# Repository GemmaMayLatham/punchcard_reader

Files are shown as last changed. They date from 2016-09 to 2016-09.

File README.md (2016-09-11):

Arduino/Raspberry Pi Punchcard reader
====

Here are the code files for the Minecraft Punchcard Reader.

This is a small box that you feed hand-punched pieces of card into
with patterns punched on them, and the program will build those patterns
inside Minecraft for you!

The Python code runs on Raspberry Pi, PC or Mac.

For a good write-up of what this project does and some really nice
photos of it in use, please see Gemma Latham's blog post here:

[Gemma's blog] (http://www.gemmamaylatham.co.uk/portfolio-item/patterncraft/)

For those of you following along with this project live, you can build
your own PunchCard reader from the materials on this website and by
looking at the photos that Gemma has posted on her blog. We hope to write
the build instructions up in detail over summer.

Inside this github repo, you will find the arduino source code for an
Arduino Pro Micro. I buy these from here:

[Sparkfun ProMicro] (http://skpang.co.uk/catalog/pro-micro-33v8mhz-with-headers-and-anyio-firmware-p-1327.html)

Inside the box I used two pieces of veroboard cut and bolted back to back
with the copper facing outwards, drilled 9 holes to line up with the
holes in the punchcard, and soldered IR transmitter LEDs on one side of
the board, and IR filtered photo transistors on the other. The LED's
and photo transistors point through the holes in the board. The Arduino
Pro-Micro then uses it's 9 analog inputs to read the voltage from each
of the Photo Transistors, and work out where the holes are in the card.

I bought these parts, 9 of each, and used 1K resistors in line with
each of them to limit the current that flows through them to an acceptable
value.

IR Transmitter LED:

[OSRAM SFH484-2] (http://uk.farnell.com/webapp/wcs/stores/servlet/ProductDisplay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)

(Note, this is now being obsoleted, use this replacement part)

[OSRAM-SFG4550] (http://uk.farnell.com/osram/sfh4550/led-ir-5mm-850nm/dp/1573495)

This replacement part is 850nm compared to the phototransistor which is 880nm,
but the spectrum overlaps enough and the two devices are only a couple of
milimeters apart, so it still works fine.

IR receiver Phototransistor:

[Fairchild QSD123] (http://uk.farnell.com/webapp/wcs/stores/servlet/ProductDisplay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)

When the card is fed in and removed, a small string of hex numbers
is sent via a serial port using PySerial at the Python end to read
these numbers. They are then decoded into CSV data and written to a text
file.

Gemma then modified Adventure 6 from the book Adventures in Minecraft
to read that file and build shapes facing upwards inside Minecraft.

I based most of the python code on the anyio library that I wrote for
the electronics chapter in the book: Adventures in Minecraft. The firmware
in the ProMicro is loaded with the firmware of this project, but it
basically works using the same techniques.

Flashing the code
====

Note that this code is only tested using Arduino IDE 1.0.5 with the 
SparkFun ProMicro from here:

https://www.sparkfun.com/products/12587

***since running ok using Arduino IDE 1.6.10

Work In Progress
====

The new all-digital code is now finished and working on the ProMicro,
and this gives us a path forward to any arduino, regardless of whether
it has any analog ports or not (we don't use them any more),
and any bit width from 1 to 8 bits (plus the necessary registration
channel that is used to sense card insertion and removal, and
blank lines with no holes punched).

The TODO list consists of:

1. Getting code running on an ATTiny85 for the one bit reader

2. Getting code running on an ATMega328P (the DIL chip as taken off
of an Arduino Uno or a Gertboard)

3. Getting the serial interface on both of the above wired up to the 
3.3V UART on the Raspberry Pi. (It should then just work out of the
box with the existing code, providing portscan.cache has the value
/dev/ttyAMA0, the config.txt has the console disabled on this port,
and the initab has the getty disabled on that port.

Note that for correctly configuring the GPIO serial port on the
Raspberry Pi, I have a ttyedit.pyc file inside this other project
that I plan to import here in source format when I have tested
everything. The script automatically checks and removes the 
console from config.txt and checks and removes the getty on the
console from initab then reboots for you:

http://blog.whaleygeek.co.uk/raspberry-pi-neopixels-colour-mixer/

The compatibility with Raspberry Pi 3 GPIO serial is yet to be
characterised, I know that they moved the uart for addition of
bluetooth, and the uart mapped to the GPIO pins used to suffer
from unexplained speed changes. This *might* have been fixed
in newer kernel releases, but I haven't tried it yet.

David Whale
@whaleygeek
June 2015

Updated May 2016

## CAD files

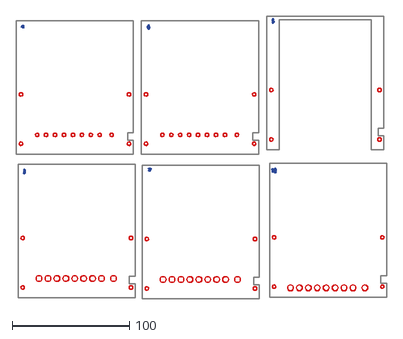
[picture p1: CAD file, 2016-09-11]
Laser files/Reader Layers 1.5mm sept.dxf
316.0 x 241.1

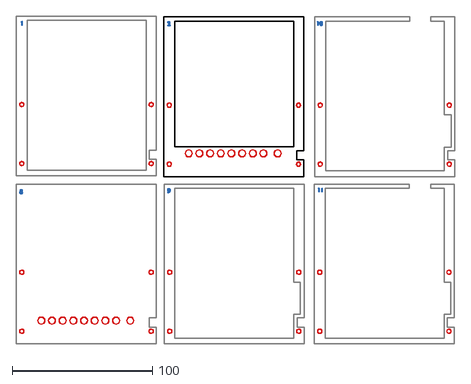
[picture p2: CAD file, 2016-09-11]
Laser files/Reader Layers 3mm sept.dxf
313.0 x 233.8

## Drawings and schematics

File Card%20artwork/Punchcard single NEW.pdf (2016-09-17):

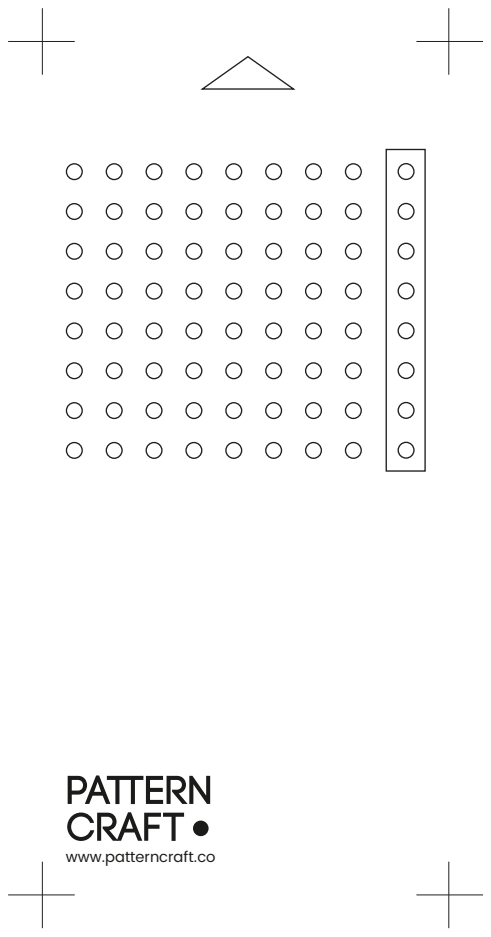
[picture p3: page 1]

www.patterncraft.co

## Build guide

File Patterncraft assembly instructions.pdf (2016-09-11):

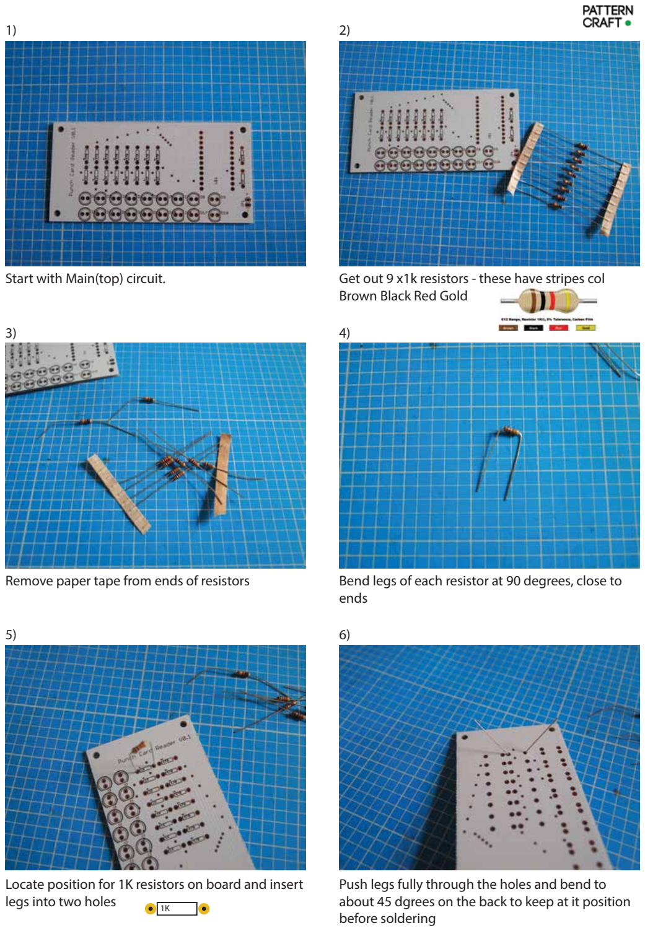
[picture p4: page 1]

Start with Main(top) circuit. | Get out 9 x1k resistors - these have stripes col Brown Black Red Gold
Remove paper tape from ends of resistors | Bend legs of each resistor at 90 degrees, close to ends

Locate position for 1K resistors on board and insert legs into two holes

Push legs fully through the holes and bend to about 45 dgrees on the back to keep at it position before soldering

1K

1) 2)
3) 4)
5) 6)

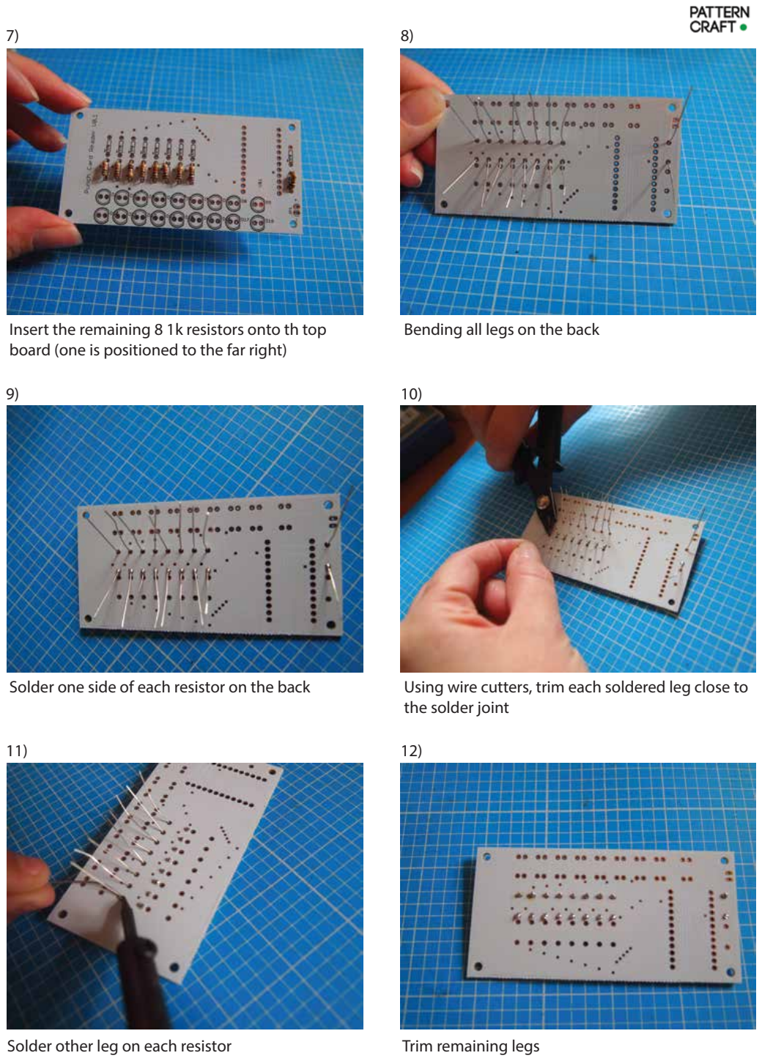
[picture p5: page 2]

Insert the remaining 8 1k resistors onto th top board (one is positioned to the far right)

Bending all legs on the back

Solder one side of each resistor on the back | Using wire cutters, trim each soldered leg close to the solder joint
Solder other leg on each resistor | Trim remaining legs
7) 8)
9) 10)
11) 12)

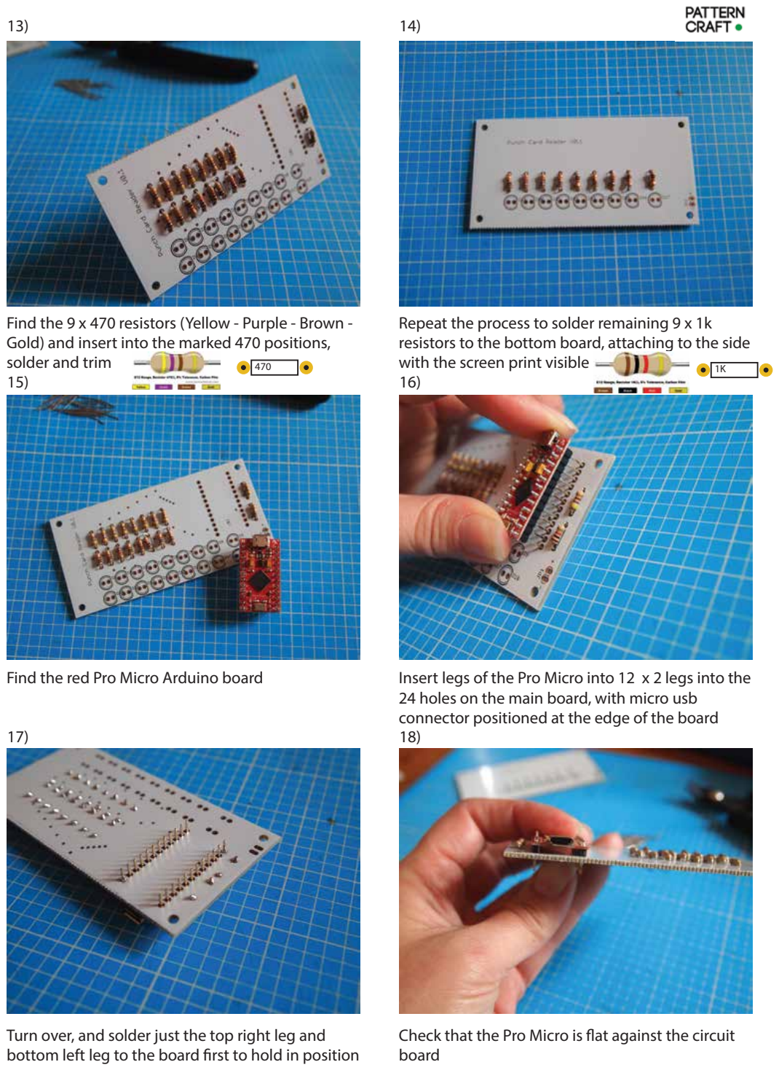
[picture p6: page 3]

Find the 9 x 470 resistors (Yellow - Purple - Brown -Gold) and insert into the marked 470 positions, solder and trim

Repeat the process to solder remaining 9 x 1k resistors to the bottom board, attaching to the side with the screen print visible

Find the red Pro Micro Arduino board | Insert legs of the Pro Micro into 12 x 2 legs into the 24 holes on the main board, with micro usb connector positioned at the edge of the board

Turn over, and solder just the top right leg and bottom left leg to the board rst to hold in position

Check that the Pro Micro is at against the circuit board

470 | 1K
13) 14)
15) 16)
17) 18)

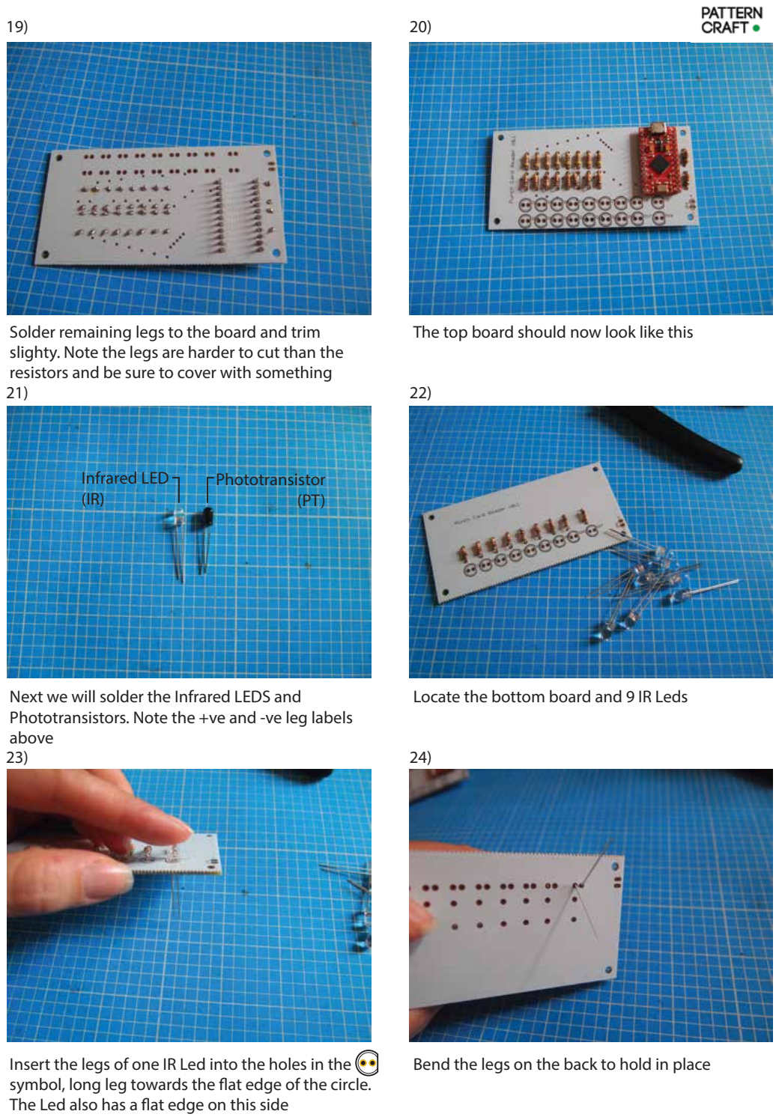
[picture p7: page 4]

Solder remaining legs to the board and trim slighty. Note the legs are harder to cut than the resistors and be sure to cover with something

The top board should now look like this

Next we will solder the Infrared LEDS and Phototransistors. Note the +ve and -ve leg labels above

Locate the bottom board and 9 IR Leds

Insert the legs of one IR Led into the holes in the symbol, long leg towards the at edge of the circle. The Led also has a at edge on this side

Bend the legs on the back to hold in place

Infrared LED
(IR)

Phototransistor
(PT)
19) 20)
21) 22)
23) 24)

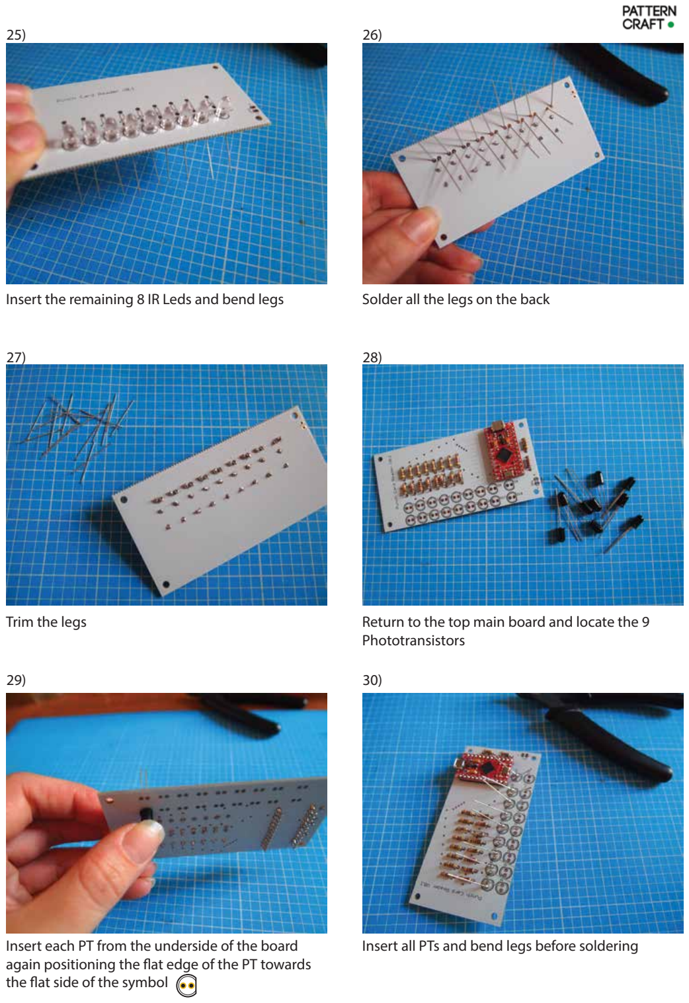
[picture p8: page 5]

Insert the remaining 8 IR Leds and bend legs | Solder all the legs on the back
Trim the legs | Return to the top main board and locate the 9 Phototransistors

Insert each PT from the underside of the board again positioning the at edge of the PT towards the at side of the symbol

Insert all PTs and bend legs before soldering

25) 26)
27) 28)
29) 30)

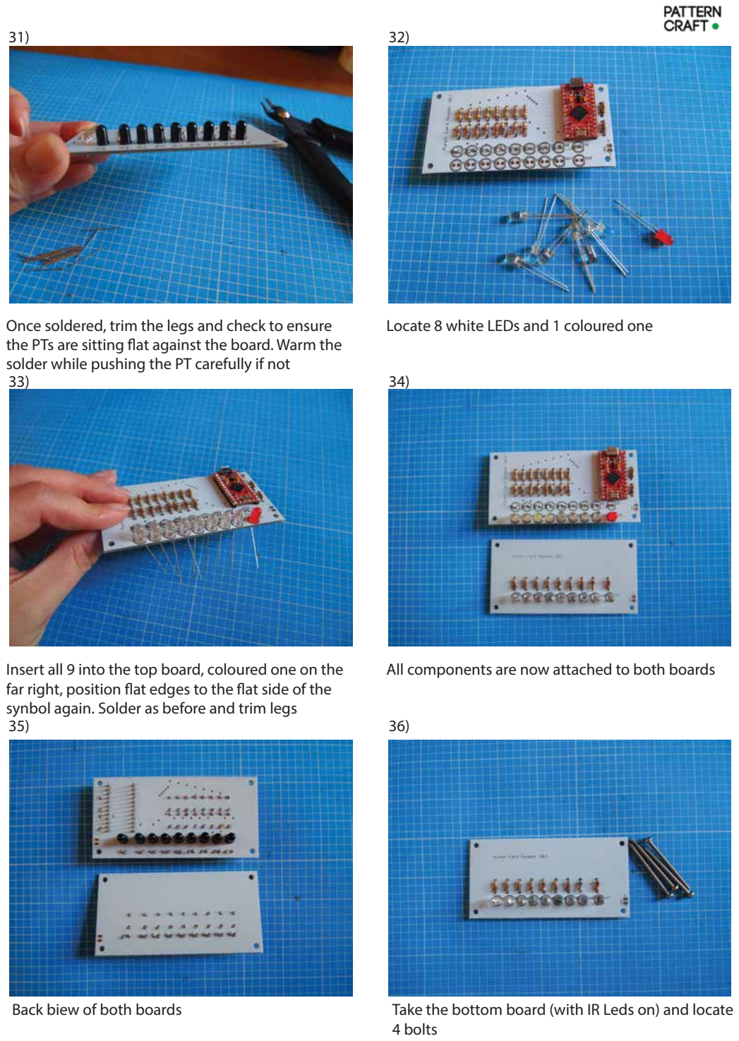
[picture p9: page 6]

Once soldered, trim the legs and check to ensure the PTs are sitting at against the board. Warm the solder while pushing the PT carefully if not

Locate 8 white LEDs and 1 coloured one

Insert all 9 into the top board, coloured one on the far right, position at edges to the at side of the synbol again. Solder as before and trim legs

All components are now attached to both boards

Back biew of both boards | Take the bottom board (with IR Leds on) and locate 4 bolts
31) 32)
33) 34)
35) 36)

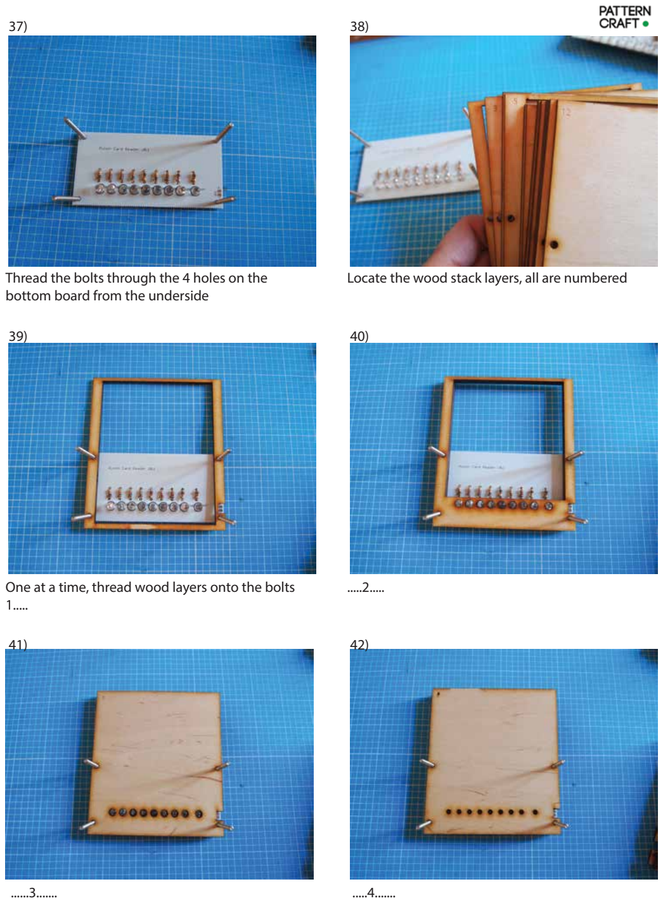
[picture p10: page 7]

Thread the bolts through the 4 holes on the bottom board from the underside

Locate the wood stack layers, all are numbered

One at a time, thread wood layers onto the bolts 1.....

.....2.....

......3....... | .....4.......
37) 38)
39) 40)
41) 42)

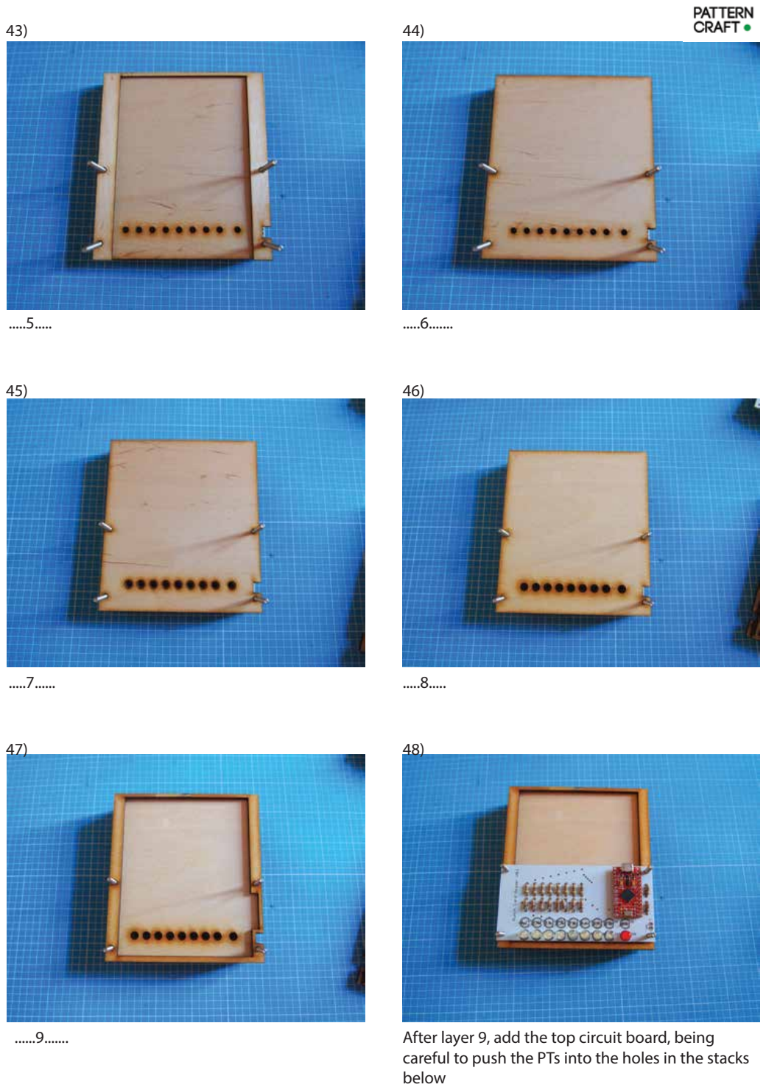
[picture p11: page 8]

.....5..... | .....6.......
.....7...... | .....8.....
......9....... | After layer 9, add the top circuit board, being careful to push the PTs into the holes in the stacks below
43) 44)
45) 46)
47) 48)

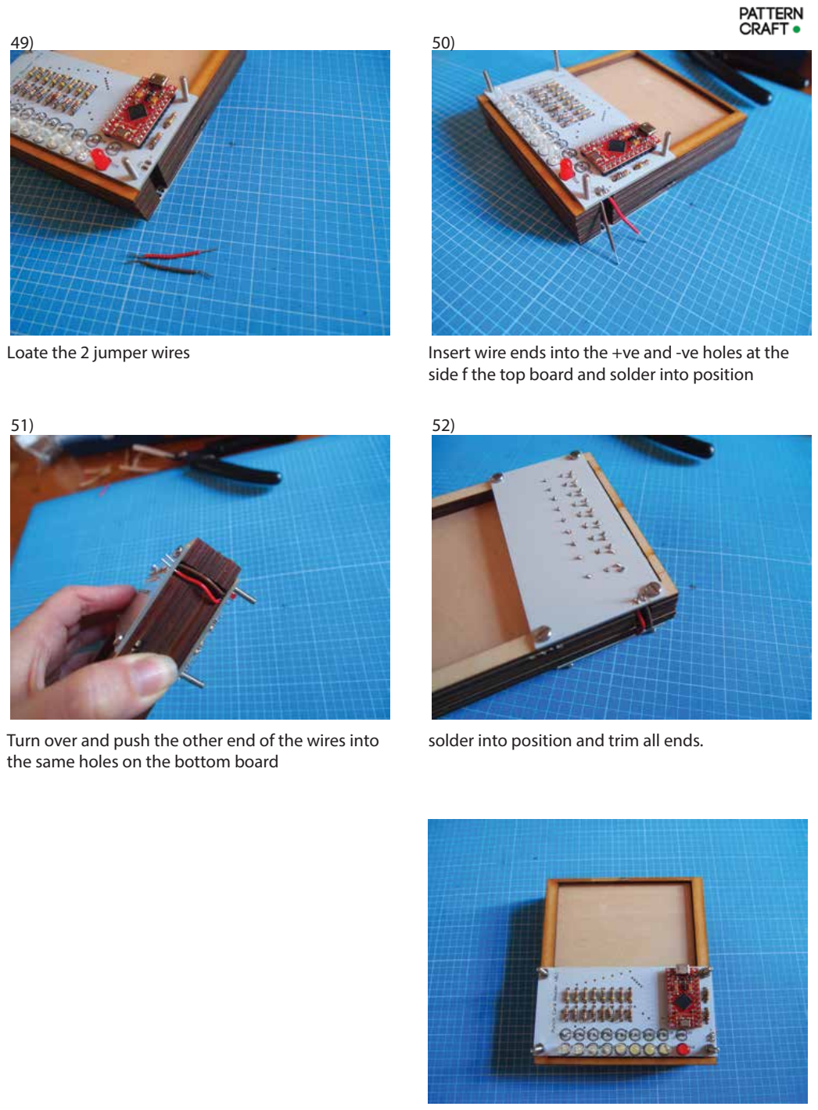
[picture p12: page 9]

Loate the 2 jumper wires | Insert wire ends into the +ve and -ve holes at the side f the top board and solder into position

Turn over and push the other end of the wires into the same holes on the bottom board

solder into position and trim all ends.

49) 50)
51) 52)

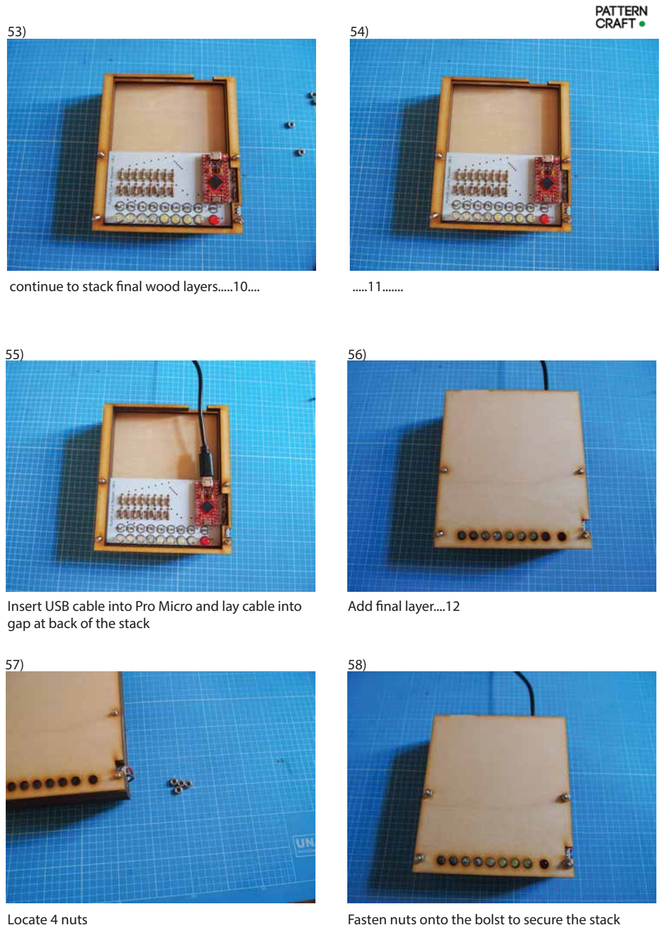
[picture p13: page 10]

Insert USB cable into Pro Micro and lay cable into gap at back of the stack

Add nal layer....12

Locate 4 nuts | Fasten nuts onto the bolst to secure the stack
continue to stack nal wood layers.....10.... | .....11.......
53) 54)
55) 56)
57) 58)

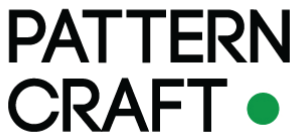
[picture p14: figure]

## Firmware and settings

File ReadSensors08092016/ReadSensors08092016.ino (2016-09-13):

// ReadSensors.ino  20/06/2015  D.J.Whale
//
// (c) 2015 D.J.Whale

// punching
// punch data in the 8 columns
// if you want an empty row, punch the REG hole
// don't punch all 8+REG else it will see a card removal


//TODO: add a record type that shows min/max values for zero's and ones on the last read
//this will be helpful to be able to diagnose problems in the field.
//min/max 1/0 for all 9 channels, in case of sensor misallignment.

// The ADC is 10 bit (0..1023)
// The photo transistors conduct when they detect IR
// So a HOLE will make the transistor conduct, current will flow, and
// the voltage at the ADC will drop, giving a value lower than this reading.
// When no card is present, all photo transistors will conduct and draw current.
// <  200 = HOLE  = 1
// >= 200 = PAPER = 0

#define CFG_SENSOR_THRESHOLD 512

//Turn on to send a raw ADC value report every time it changes
//#define CFGEN_SEND_ADC_REPORTS

//Turn this on to turn a state change report every state change
//#define CFGEN_SEND_STATE_REPORTS

//Turn this on to send row data reports every detected row
//#define CFGEN_SEND_ROW_REPORTS

// Pinouts for Sparkfun ProMicro:
// https://learn.sparkfun.com/tutorials/pro-micro--fio-v3-hookup-guide/hardware-overview-pro-micro

#define NUM_CHANNELS 9
#define REG          8  // A8
#define D7           7  // 7
#define D6           6  // A7
#define D5           5  // 5
#define D4           4  // A6
#define D3           3  // 3
#define D2           2  // 2
#define D1           0  // RX
#define D0           1  // TX

#define LED_REG      A3 // 21
#define LED_D7       A2 // 20
#define LED_D6       A1 // 19
#define LED_D5       A0 // 18
#define LED_D4       15 // SCLK
#define LED_D3       14 // MISO
#define LED_D2       16 // MOSI
#define LED_D1       10 // A10
#define LED_D0       9  // A9

// Set to 8, will only read IN phase
// Set to 16, will read and collect OUT phase also
// Must see all CARD_ROWS rows to get a OK report
// if less rows read, will get an error, but data still included
// This allows host to compare IN and OUT phases and error correct
#define CARD_ROWS    16

#define REPORT_OK_BOOT       0x00
#define REPORT_OK_CARD       0x01
#define REPORT_OK_STATE      0x02
#define REPORT_OK_ROW        0x03
#define REPORT_OK_ADC        0x04
#define REPORT_ERR_LENGTH    0x81

typedef enum 
{
  STATE_NOCARD = 0,
  STATE_INSERTING,
  STATE_WAITING_ROW,
  STATE_IN_ROW,
  STATE_GAP,
  STATE_REMOVING,
  STATE_END
} STATE;

byte sticky = 0;
boolean seenReg = false;
byte row = 0;
byte card[CARD_ROWS];
unsigned int adc[NUM_CHANNELS];
STATE state = STATE_NOCARD;
STATE prev = STATE_NOCARD;


void setup()
{
  Serial.begin(115200);  
  
  pinMode(LED_REG, OUTPUT);
  pinMode(LED_D7,  OUTPUT);
  pinMode(LED_D6,  OUTPUT);
  pinMode(LED_D5,  OUTPUT);
  pinMode(LED_D4,  OUTPUT);
  pinMode(LED_D3,  OUTPUT);
  pinMode(LED_D2,  OUTPUT);
  pinMode(LED_D1,  OUTPUT);
  pinMode(LED_D0,  OUTPUT);
  sendCardReport(REPORT_OK_BOOT, NULL, 0);
}


void loop()
{  
  readADCs();
  
  // Generate filtered versions of registration and data
  byte freg = getData(adc[8], 0);  
  byte now  = getData(adc[7], 7) | getData(adc[6], 6) | getData(adc[5], 5) | getData(adc[4], 4)
            | getData(adc[3], 3) | getData(adc[2], 2) | getData(adc[1], 1) | getData(adc[0], 0);

  // Show live diagnostics on LEDs
  writeLEDs(freg, now);

#if defined(CFGEN_SEND_ADC_REPORTS)
  if (now != sticky)
  {
    Serial.write(':');
    Serial.write(REPORT_OK_ADC);
    for (int i=8; i>=0; i--)
    {
      //in decimal ADC values are 10 bits (3 nybbles)
      Serial.print(adc[i]);
      Serial.print(" ");
    }
    Serial.println();
  }
#endif

  
  // crank round the acquisition state machine
  switch (state)
  {
    case STATE_NOCARD:
      // stay here while freg=1 and data=0xFF, all holes (card removed)
      if ((freg != 1) || now != 0xFF)
      { // at least one sensor has seen paper
        state = STATE_INSERTING;
        //Serial.println(state);
      } 
    break;
    
    case STATE_INSERTING:
      // check for early removal (all holes)
      if ((freg == 1) && (now == 0xFF))
      {
        // bail early if all on (removed)
        state = STATE_REMOVING;
        //Serial.println(state);
      }
      // wait for all paper
      else if ((freg == 0) && (now == 0x00))
      {
        row = 0;
        state = STATE_WAITING_ROW;
        //Serial.println(state);
      }
    break;
    
    case STATE_WAITING_ROW:
      // check for early card removal (all reading holes)
      if ((freg == 1) && (now == 0xFF))
      {
        state = STATE_REMOVING;
        //Serial.println(state);
      }
      else
      { // wait for any data to start appearing (at least one hole)
        if ((freg == 1) || (now != 0x00))
        {
          sticky  = now;
          state   = STATE_IN_ROW;
          //Serial.println(state);
        }
      }
    break;
    
    case STATE_IN_ROW:
      // check for early card removal (all holes)
      if ((freg == 1) && (now == 0xFF))
      {
        state = STATE_REMOVING;
        //Serial.println(state);
      }
      else
      {
        // remember if we see the registration hole while reading a row
        // this is only punched if the row is completely unpunched
        // that way we don't miss the row
        if (freg == 1)
        {
          seenReg = true;
        }
        // keep collecting sticky bits until all go zero again
        sticky |= now;
        if ((freg == 0) && (now == 0x00))
        {
          state = STATE_GAP;
          //Serial.println(state);
        }  
      }
    break;
    
    case STATE_GAP:
#if defined(CFGEN_SEND_ROW_REPORTS)
      {
         byte report[2];
         report[0] = row;
         report[1] = sticky;
         sendCardReport(REPORT_OK_ROW, report, sizeof(report));
      }
#endif      
      // store row data in card buffer
      card[row] = sticky;
      // advance row
      row += 1;
      // more rows?
      if (row == CARD_ROWS)
      {
        state = STATE_END;
        //Serial.println(state);
      }
      else
      {
        state = STATE_WAITING_ROW;
        //Serial.println(state);
      }
    break;
    
    case STATE_END:
      // wait here until card removal
      // Note, later version will read on way out again, and complare in and out readings
      if ((freg == 1) && (now == 0xFF))
      {
        sendCardReport(REPORT_OK_CARD, card, CARD_ROWS);
        state = STATE_NOCARD;
        //Serial.println(state);
      }
    break;
    
    case STATE_REMOVING:
      // only report the rows that were read
      sendCardReport(REPORT_ERR_LENGTH, card, row);
      state = STATE_NOCARD;
    break;
  }  
  
  if (state != prev)
  {
    prev = state;
#if defined(CFGEN_SEND_STATE_REPORTS)
    {
      byte report = (byte) (state & 0xFF);
      sendCardReport(REPORT_OK_STATE, &report, 1);
    }
#endif
  }
}


byte readADCs(void)
{
  // Read all 9 inputs (roughly) at same time

  //temp fix for non analog ports
  if(digitalRead(REG)){adc[8]=1023;}else{adc[8]=0;}
  if(digitalRead(D7)){adc[7]=1023;}else{adc[7]=0;}
  if(digitalRead(D6)){adc[6]=1023;}else{adc[6]=0;}
  if(digitalRead(D5)){adc[5]=1023;}else{adc[5]=0;}
  if(digitalRead(D4)){adc[4]=1023;}else{adc[4]=0;}
  if(digitalRead(D3)){adc[3]=1023;}else{adc[3]=0;}
  if(digitalRead(D2)){adc[2]=1023;}else{adc[2]=0;}
  if(digitalRead(D1)){adc[1]=1023;}else{adc[1]=0;}
  if(digitalRead(D0)){adc[0]=1023;}else{adc[0]=0;}
  
//  adc[8] = analogRead(REG);
//  adc[7] = analogRead(D7);
//  adc[6] = analogRead(D6);
//  adc[5] = analogRead(D5);
//  adc[4] = analogRead(D4);
//  adc[3] = analogRead(D3);
//  adc[2] = analogRead(D2);
//  adc[1] = analogRead(D1);
//  adc[0] = analogRead(D0);
}


byte getData(unsigned int adc, byte bitno)
{
  if (adc < CFG_SENSOR_THRESHOLD) return (1<<bitno);
  return 0;
}

long unsigned int pulseCounter=0;

void writeLEDs(byte reg, byte data)
{
  // Show card data on feedback LEDs - these have been pulsed to increase LED lifetime.
  if(pulseCounter%8==0){
    digitalWrite(LED_REG, reg);
    digitalWrite(LED_D7,  data&(1<<7));
    digitalWrite(LED_D6,  data&(1<<6));
    digitalWrite(LED_D5,  data&(1<<5));
    digitalWrite(LED_D4,  data&(1<<4));
    digitalWrite(LED_D3,  data&(1<<3));
    digitalWrite(LED_D2,  data&(1<<2));
    digitalWrite(LED_D1,  data&(1<<1));
    digitalWrite(LED_D0,  data&(1<<0));
  }else{
    digitalWrite(LED_REG, 0);
    digitalWrite(LED_D7, 0);
    digitalWrite(LED_D6, 0);
    digitalWrite(LED_D5, 0);
    digitalWrite(LED_D4, 0);
    digitalWrite(LED_D3, 0);
    digitalWrite(LED_D2, 0);
    digitalWrite(LED_D1, 0);
    digitalWrite(LED_D0, 0);
  }
  pulseCounter++;
}


void sendCardReport(byte type, byte* pData, byte len)
{
  Serial.write(":"); // Start char
  sendHexByte(type); // mandatory type
  
  // Show optional data of any length
  for (byte i=0; i<len; i++)
  {
    sendHexByte(pData[i]);
  }
  Serial.println(); // End char
}


void sendHexByte(byte val)
{
  Serial.write(tohexch(val>>4)); // high nybble
  Serial.write(tohexch(val));    // low nybble
}


char tohexch(byte val)
{
  val = val & 0x0F;
  if (val > 9)
  {
    return 'A' + (val-10);
  }
  else
  {
    return '0' + val;
  }
}

/* END OF FILE */

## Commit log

2016-09-11 Revised code for 8 bit reader only
    LEDs now set to blink
2016-09-11 New version of 8 bit reader code
    LEDs set to blink now
2016-09-11 Laser cut artwork for stackable layers with PCB
    [Reader Layers 1.5mm sept.dxf, Reader Layers 3mm sept.dxf]
2016-09-11 Update README.md
    confirmed working on latest version of Arduino IDE (1.6.10)
2016-09-13 updated pin desciptions
